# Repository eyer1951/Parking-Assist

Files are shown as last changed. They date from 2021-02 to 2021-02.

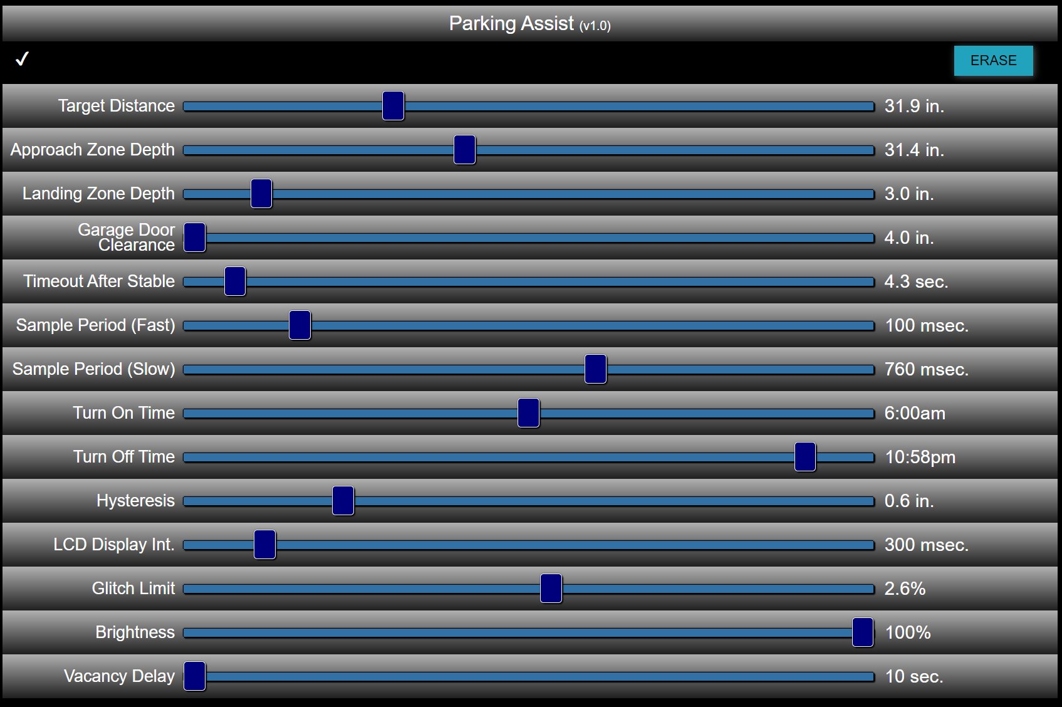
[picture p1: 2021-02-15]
images/web-app.jpg

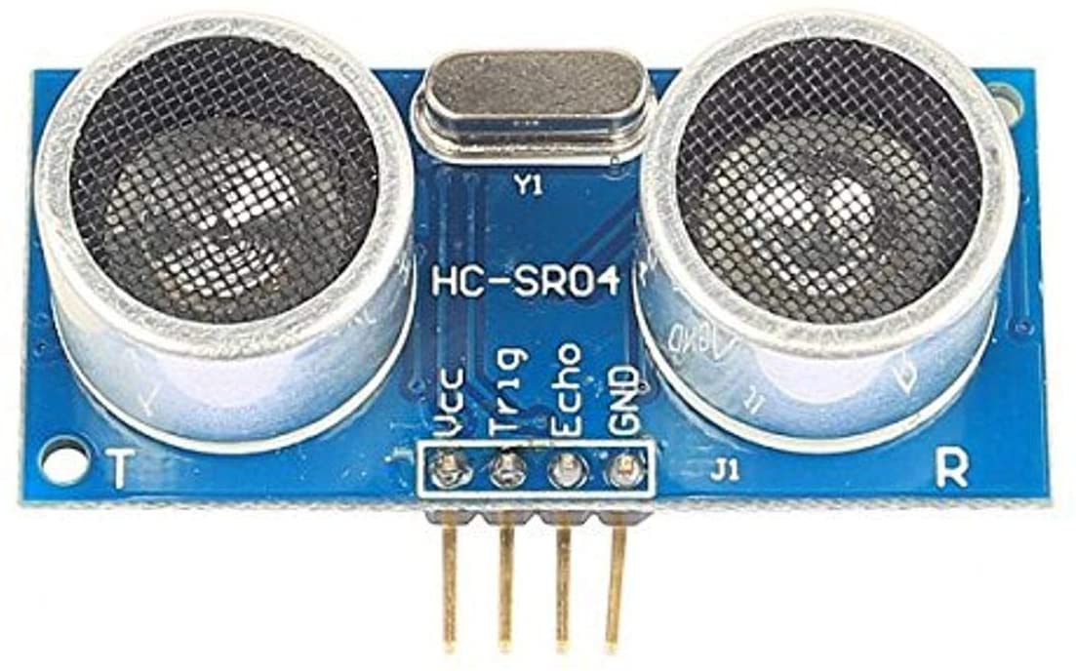
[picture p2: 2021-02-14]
images/HC-SR04_.jpg

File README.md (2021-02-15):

# Parking-Assist
ESP32-based parking assistant using ultrasonic distance measurement and a multi-LED display
This project was an opportunity to combine several hardware/software technologies to create something I use every day. 
The Parking Assist unit used an HC-SR04 ultrasonic distance sensor to help signal the precise positioning of the car 
as it is moved into the garage. The unit was mounted on the side of a file cabinet in front of my parking space.
Here's a view from inside the car as the driver pulls in:



Technologies, in addition to the use of the HC-SR04, include:

*	Control of an addressable (WS2812B) LED strip via the FastLED library

*	Sensing the ambient air temperature to compute an accurate speed of sound for distance measurement

*	WiFi connection to the home network for control

*	Setting the “target” parking distance via pushbutton

*	Setup of parameters by web application

*	Web application implemented an approach where the characteristics of the set of control parameters were defined in a JSON file

*	Websocket interface for delivery of parameters

*	A telnet interface for debugging and/or monitoring the status of the unit from within the home network

*	Supported ArduinoOTA for code downloads over the network

*	mDNS for network address discovery

*	Parameters retained in the ESP32 using nonvolatile storage in the ESP32

*	A real-time clock, synchronized to an NTP time server, to turn off the unit during off-hours

*	Printed circuit board designed to fit within a standard plastic enclosure

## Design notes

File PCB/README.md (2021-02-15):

# Printed Circuit Board

The Fritzing (BETA version 0.9.3) program was used to create a PCB design, pictured here:



Extended Gerber (RS-274X) files were created and delivered to a PC fab house, PCBWay (pcbway.com), 
which delivered 10 boards in under one week at a total cost of $25 (including shipping).

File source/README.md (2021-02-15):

# ESP32 Source Code

The code was written in C++ using the PlatformIO development environment running in Visual Studio Code. 
There are four main files in the source:

* main.css – the main program, including setup() and loop().
 
* main.h – a header file defining some project-related items used by the project.css file, and defining the array of parameters used.

* project.css – code implementing functions common to many projects, including:

  *	NVS-related functionality including initialization, saving and restoring parameters
  *	Some helpful utility functions
  * mDNS-related functionality
  *	WiFi connection functions, including reconnection upon lost connection
  *	Over-the-air (OTA) code download functionality
  *	WebSockets functionality supporting the parameter array approach

* project.h – header file for the project, providing procedure declarations and definition of a Ring buffer class.

Library dependencies are:

* adafruit/Adafruit Unified Sensor, version 1.1.4 or above

* adafruit/DHT sensor library version 1.4.1 or above

*	arduino-libraries/NTPClient version 3.1.0 or above

*	m5ez/ezTime version 0.8.3 or above

*	fastled/FastLED version 3.4.0

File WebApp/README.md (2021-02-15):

# Web Application

For all of the different ESP32 projects I have built so far, it has been helpful to provide a user interface whereby various operating parameters could be set, 
and adjusted over time as needed. A general approach was developed, involving:

*	A browser-based user interface written in (of course) Javascript and HTML/CSS.

*	Use of Websockets to communicate between the project and the browser.

*	The ESP32 discovers and connects to the home network in station mode, sets up an mDNS identifier for TCP/IP, and then opens a WebSocket interface.

*	Parameters are represented by an array of up to 30 unsigned 32-bit integers.

*	The web application uses the mDNS ID to establish a WebSocket connection, then queries the project to retrieve the values of all parameters.

*	The ESP32 saves all parameters in nonvolatile storage (NVS).

*	Changes to any parameter are delivered immediately via the Websocket interface and saved in the ESP32 in NVS.

*	The set of parameters and definitions for the project are defined in a JSON document opened by the web application.

Note: because it loads a local JSON file, the web application must be served from a web server on your network rather than being executed as a file on 
the local computer (that is, unless you run the browser with “same origin policy” disabled). 
Otherwise you might see this kind of error in the JavaScript console: 

```Access to XMLHttpRequest at 'file:///C:/Users/ … /projectName.json' from origin 'null' has been blocked by CORS policy: Cross origin requests are only supported for protocol schemes: http, data, chrome, chrome-extension, chrome-untrusted, https.```

The JSON document, in addition to defining the name of the project (for the web page title), version number, and mDNS name, 
defines a number of operating parameters. Operating parameters can be values representable by range sliders, Boolean flags 
(represented by checkboxes), or colors established by “color picker” interface. The web interface for the present project did 
not utilize any checkboxes or color pickers and is shown here:

![](images/web-app.jpg)

The checkmark in the upper left indicates connectivity to the project. The “ERASE” button in the upper left is used to command the project to erase NVS, if needed.
The JSON document defines a number of characteristics of each range slider, including:

*	The name (label on left side)

* The minimum and maximum values of the slider.

*	The step size 

As an example of the latter, the time of day parameters are represented as a number of minutes since midnight, so a parameter that would represent midnight to noon would be specified with a range that goes from zero to 12 * 60 = 360. The name of that display function is “timeOfDay.” Other example display functions are:

*	percent – displays the slider as a whole percentage, where zero is all the way to the left and 100 is all the way to the right.

*	percentTenths – displayed as percent as above, but as a floating point number with one digit to the right of the decimal

*	tenths – displays the value of the slider, but divided by 10.

Other functions can be easily written as needed.

CSS can be included in the JSON definition of any range slider, to provide, for example, a horizontal bar or extra space associated with a given slider.
A link to the JSON document that produced the user interface above is https://github.com/eyer1951/Parking-Assist/blob/main/WebApp/pc/parkme.json.

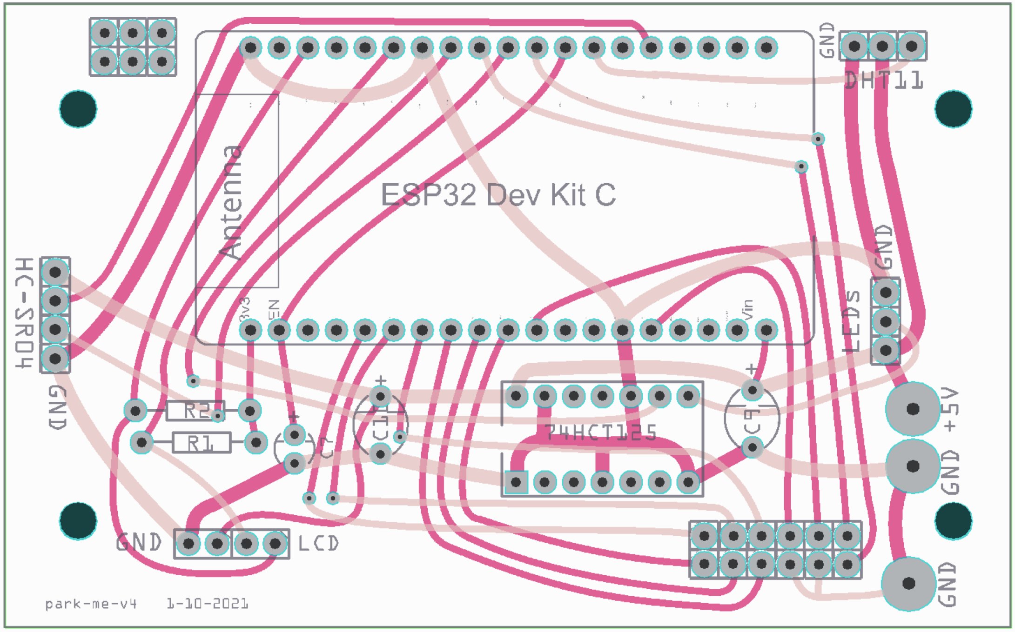
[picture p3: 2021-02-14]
images/PCB-gerber.jpg

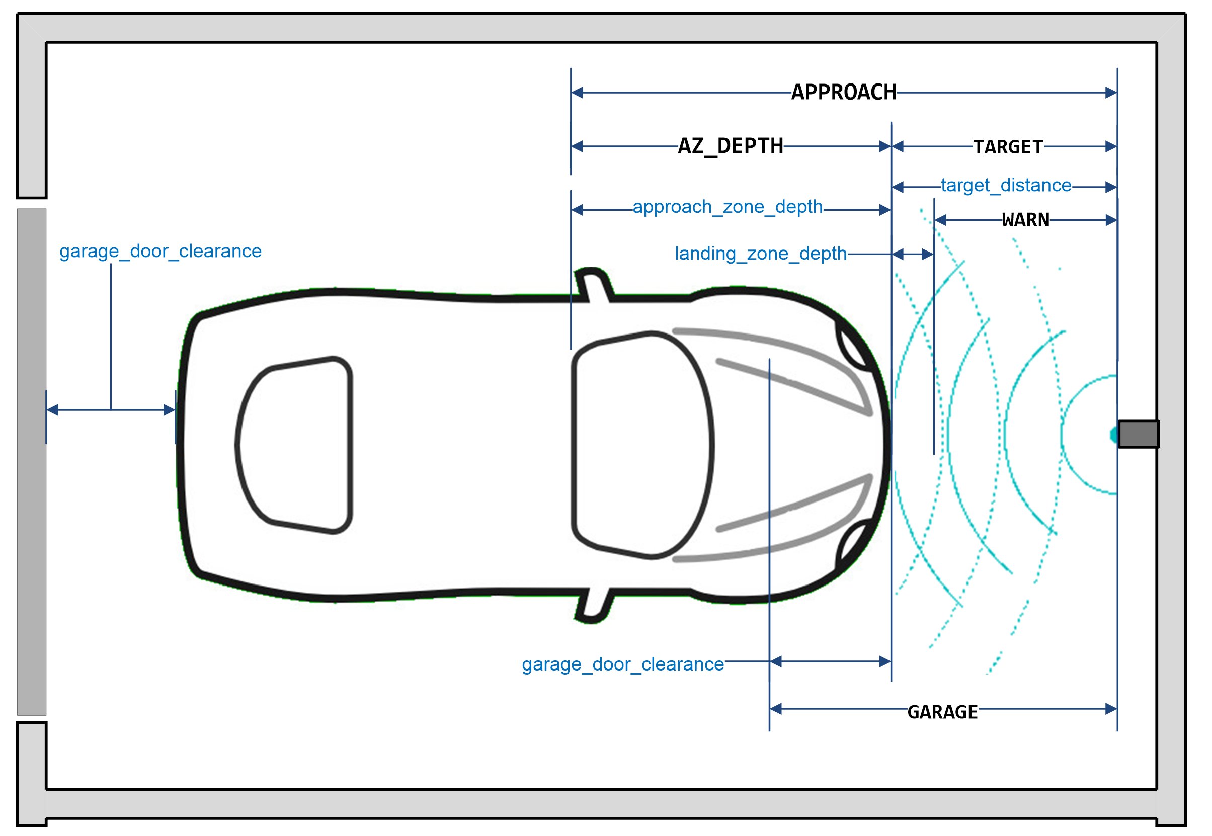
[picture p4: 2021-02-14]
images/Garage-params.jpg

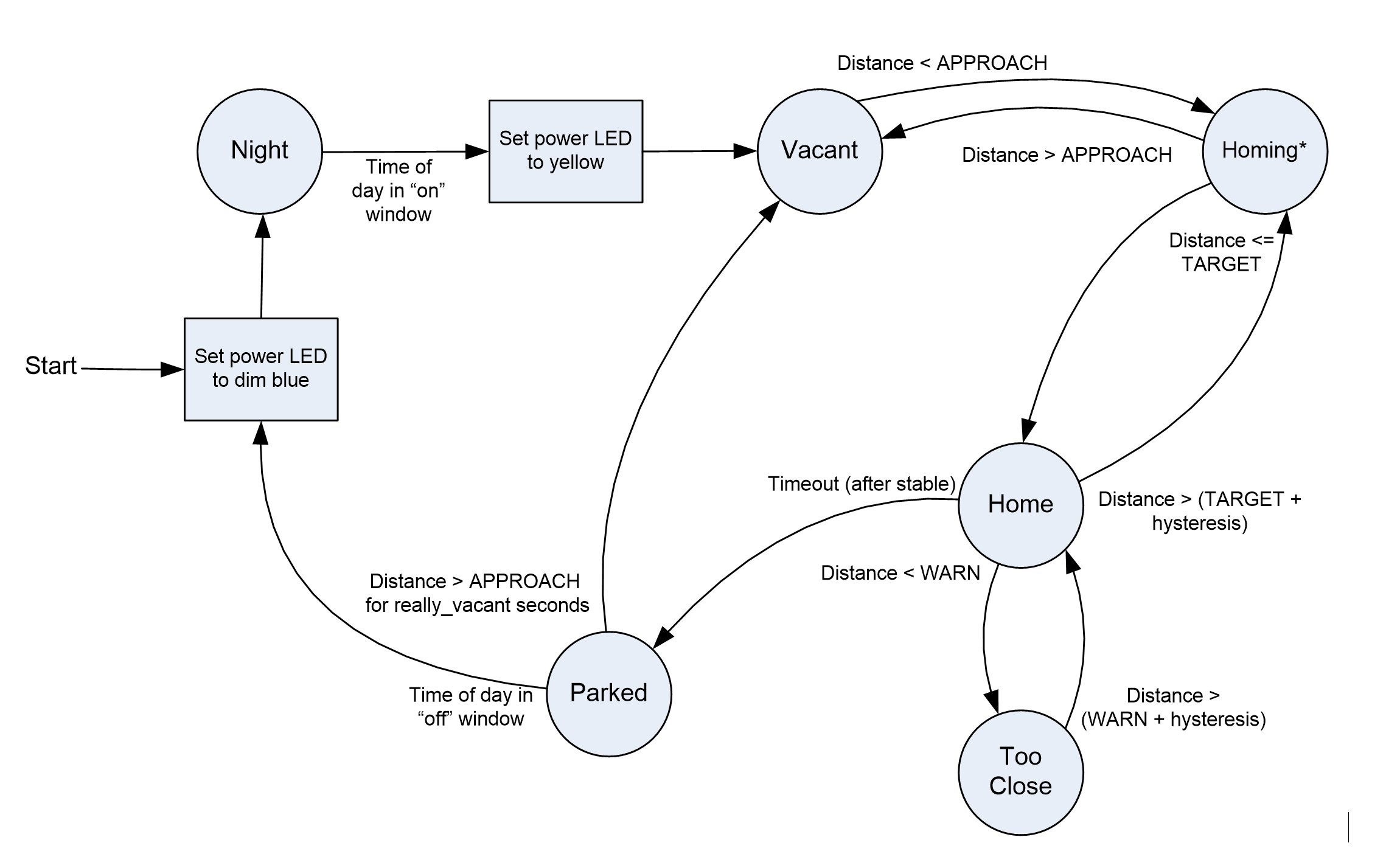
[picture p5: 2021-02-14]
images/Park-state-machine.jpg

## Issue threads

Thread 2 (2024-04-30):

Does anyone one have the file to flash the esp32?

TechsavvyCNC, 2024-04-30:
I'm having a lot off issues trying to build it on my own

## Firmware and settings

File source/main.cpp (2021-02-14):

/*Name:		Park-the-car.cpp
Created:	2/5/2021  1:40PM

STATUS:
    * Connects to home network, reconnects daily after network returns
    * API to control color of LED(s) 
      * (blink on startup to indicate code version)
    * Synchronizes to local time of day (including DST)
    * OTA upload 
    * Temperature, humidity, and distance sensor working
    * Turn system on in the morning and off at night based on settable parameters
    * Lower the sample rate to once every N msec. whenever distance is 
        * greater than threshold or less than threshold
    * Control color of LED (green to red) based on threshold values
    *   Or: number of LEDs lit in a strip
    * Blink red if beyond the "too close" threshold
    * Control of hysteresis
    * Control of brightness level when Homing
    * Supports Telnet connection, "D" command to report last 48 distance measurements
    * Supports mDNS, with "Parkme.local" (or "Parkme2.local") as host ID
*/
char version[] = "Park v1.14";

#include <Arduino.h>
#include <ArduinoOTA.h>
#include <ezTime.h>
#include <stdio.h>
#include <stdlib.h>
#include <string.h>
#include <cstring>
#include <math.h>
#include "driver/gpio.h"
#include "soc/gpio_struct.h"
#include "nvs.h"
#include "nvs_flash.h"

#define FASTLED_INTERNAL
#include <FastLED.h>
#include <Adafruit_Sensor.h>    // https://github.com/adafruit/Adafruit_Sensor
#include <DHT.h>                // https://github.com/adafruit/DHT-sensor-library
#include <LiquidCrystal_I2C.h>  // Library for LCD

#include "main.h"
#include "project.h"

//------------------------------------------ Options -------------------------------------------------
#define ENABLE_TIME_OF_DAY
// #define ENABLE_LCD

//----------------------------------------- GPIO Assignments -----------------------------------------
#define DHTPin 4        // I/O Pin for DHT11 Humiture unit 
#define DHTPin_ALT 26   // Alternate DHT11 pin (if GPIO4 doesn't work for all ESP32s)
#define DHTType DHT11   // Define DHT sensor type

#define trigPin 2       // I/O Pins for HC-SR04 Ultrasonic Distance Unit
#define echoPin 5

#define BUTTON_PIN 13   // Pushbutton is on GPIO13

#ifdef ENABLE_LCD
// Connect to LCD via i2c, default address 0x27 (A0-A2 not jumpered):
// LCD uses default i2c pins:  SCLPin = 22  SDAPin = 21
LiquidCrystal_I2C lcd = LiquidCrystal_I2C(0x27, 16, 2);
#endif

//------------------------------------------- DEBUG Items --------------------------------------------
#define CORE_DEBUG_LEVEL ESP_LOG_ERROR
#define GPIO_DEBUG
#define DEBUG_TICKS 1 /* How many cycles debug_time > 0 */
#define DEBUG_INTERVAL_MS 500
volatile int debug_time = 0;

// ------------------------------------------- LED STUFF ---------------------------------------------
#define NUM_LEDS 16
#define NUM_STRANDS 1 

#define COLOR_ORDER GRB
#define CHIPSET WS2812B
#define BRIGHTNESS 128
#define MAX_BRIGHTNESS 255
#define MY_CORRECTION 0xFEC886 /* set by testing */
#define RMT_CH0_GPIO 19
#define MAX_LED_BRIGHTNESS parameters[max_led_brightness_pct] * 255 / 100
static CRGB leds[NUM_STRANDS][NUM_LEDS + 1];  // the +1 holds overflow (not visible)

//---------------------------------------------- Globals ---------------------------------------------
using namespace std;

#define PRESSED LOW
#define NOT_PRESSED HIGH

typedef struct Buttons {
    const byte pin = BUTTON_PIN;
    const int debounce = 10;
 
    unsigned long counter=0;
    bool prevState = NOT_PRESSED;
    bool currentState;
} Button;
 
// create a Button variable type
Button button;

long duration;
float distance_cm;
float distance_in;
float distance_ft;
float speedofsound;
float parked_at;
float state_distance;

int temperature;
unsigned long msnow = millis();
unsigned long home_time_ms;

extern nvs_handle my_nvs_handle;
extern Params parameters;
extern WebSocketsServer webSocket;
extern char base_hostname[30];

const char *base_ssid = BASE_SSID;
const char *base_password = BASE_PASSWORD;

#ifdef ENABLE_TIME_OF_DAY
Timezone myTZ;
int hour_now = myTZ.hour();
int minute_now = myTZ.minute();
int second_now = myTZ.second();
#endif

// Queue of distance measurements, for smoothing
int dist_iptr = 0;
int dist_optr = 0;
#define DIST_Q_DEPTH 100
float distances[DIST_Q_DEPTH];

// Blink warning
#define BLINK_INTERVAL 300  // milliseconds
bool blink;

typedef Ring<float> Ringf;
typedef Ring<long> Ringi;

Ringf samples_f(DIST_Q_DEPTH);
Ringi samples_i(DIST_Q_DEPTH);
int skipped = 0;
int skipped_total = 0;

//------------------------------------------ Parameters ----------------------------------------------
Parameter params[NO_OF_PARAMS] = {{"target distance (tenth in.)", 450},
                                  {"approach zone depth (tenth in.)", 480},
                                  {"landing zone depth (tenth in.)", 50},
                                  {"garage door clearance (tenth in.)", 100},
                                  {"timeout after stable (sec.)", 600},
                                  {"high precision sample rate (msec.)", 200},
                                  {"background sample rate (msec.)", 1500},
                                  {"time turn on (minutes since midnight)", 70},
                                  {"time turn off (minutes since midnight)", 230},
                                  {"hysteresis (tenth in.)", 15},
                                  {"lcd display interval (msec.)", 300},
                                  {"glitch limit (pct. x10)", 50},
                                  {"brightness (pct.)", 100},
                                  {"vacancy delay (sec.)", 60}};

//------------------------------------------ State Machine -------------------------------------------
enum State {Night, Vacant, Homing, Home, TooClose, Parked};
State state = Night;

unsigned long display_interval, measurement_interval;
SemaphoreHandle_t xSemaphore_d = NULL;   // distance
SemaphoreHandle_t xSemaphore_t = NULL;   // temperature

#define TEMP_MEASUREMENT_INTERVAL_MS  1000 * 60 /*  1000 * 60 * 5 5 minutes */

#define LONG_TIME 0xFFFFFF

#define UNIT_NO_PIN 27  /* Pulldown when not the one in the garage; for testing */

extern WiFiClient serverClient;
extern tcpip_adapter_ip_info_t info;

DHT dht1(DHTPin, DHTType);
DHT dht2(DHTPin_ALT, DHTType);
DHT *dhtp;
int unit_no;

//-------------------------------------------- LCD Stuff ---------------------------------------------
#ifdef ENABLE_LCD
SemaphoreHandle_t xSemaphore_l = NULL;   // LCD
#define LCD_BUFFSIZE 20
char buffer1[LCD_BUFFSIZE];  // LCD line 1
char buffer2[LCD_BUFFSIZE];  // LCD line 2
#define LCD_DISPLAY_INTERVAL parameters[lcd_display_interval_ms]

void display_off_on_lcd() {
    memset(buffer1, 0, sizeof(buffer1));
    strcpy(buffer1, "off");
    memset(buffer2, 0, sizeof(buffer2));
}
#endif

//------------------------------------------- Telnet -------------------------------------------------
// Telnet
WiFiServer server(23);
WiFiClient serverClient;

// ------------------------------------------ Telnet Print -------------------------------------------
template<typename... Args> void telnet_printf(const char * f, Args... args) {
    char cbuff [360];
    int len;
    if (serverClient || serverClient.connected()) {
        len = sprintf(cbuff, f, args...);
        if (cbuff[len-1] == '\n') cbuff[len++] = '\r';
        serverClient.write(cbuff, len); 
    }
}

template<typename... Args> void tprintf(const char * f, Args... args) {
    printf(f, args...);
    telnet_printf(f, args...);
    telnet_printf("\r");
}

void handle_telnet_command(char c) {
    float items[51], a;
    string results = "";
    char one_item[30];
    int i, n;
    switch (c) {
        case 'D':
        case 'd':
            n = samples_f.get_last_n(49, items);
            for (i = 0; i < 49; i ++) {
                if (i < n) {
                    sprintf(one_item, "%.1f, ", items[i]);
                    results += one_item;
                }
            }
            a = samples_f.average(4);
            telnet_printf("%s (%.1f)\n\r", results.c_str(), a);
            break;
        default:
            break;
    }
}

void new_telnet_client() {
    if (WiFi.status() == WL_CONNECTED) {
        if (server.hasClient()) {
            if (!serverClient || !serverClient.connected()) {
                if (serverClient) serverClient.stop();
                serverClient = server.available();
                if (!serverClient) printf("available broken\n");
                telnet_printf("New telnet client: %s\n\r", serverClient.remoteIP().toString().c_str());
                telnet_printf("\n\e[0;32mConnected to %s on channel %i\e[0m\n\r", BASE_SSID, WiFi.channel());
                tcpip_adapter_get_ip_info(TCPIP_ADAPTER_IF_STA, &info);
                telnet_printf("Got IP address %s\n\r", ip4addr_ntoa(&info.ip));
            }
        }
        if (serverClient && !serverClient.connected()) {
            serverClient.stop();
        }
    }
}

void check_telnet_data() {
    char cbuff[10];
    if (serverClient && serverClient.connected()) {
        if (serverClient.available()) {
            while (serverClient.available()) {
                cbuff[0] = serverClient.read();
                handle_telnet_command(cbuff[0]);
            }
        }
    }
}

//------------------------------------------ Button Handler ------------------------------------------
void handle_button_press() {
    float where_we_are = samples_f.average(samples_f.fullness()-1);
    parameters[target_distance_10th_in] = (int)(0.5 + where_we_are * 10.0);
    tprintf("New target distance set to %.1f inches (%i)\n", where_we_are, parameters[target_distance_10th_in]);
    send_parameters(255);
    save_params();
}

void check_button() {
    button.currentState = digitalRead(button.pin);    // check the button
    if (button.currentState != button.prevState) {    // has it changed?
        delay(button.debounce); 
        button.currentState = digitalRead(button.pin);  // update status in case of bounce
        if (button.currentState == PRESSED) { // has a new press event occured?
            handle_button_press();
        }
        button.prevState = button.currentState; // used to detect when state changes
    } 
}

//------------------------------------------ Time of Day ---------------------------------------------
#ifdef ENABLE_TIME_OF_DAY
void wait_for_local_time() {
	//setDebug(INFO);
	waitForSync();
	printf("UTC:         %s\n", UTC.dateTime().c_str());
	// https://en.wikipedia.org/wiki/List_of_tz_database_time_zones
	myTZ.setLocation(F(MY_TIME_ZONE));
	printf(MY_CITY ":     %s\n", myTZ.dateTime().c_str());
}
#endif

bool during_the_day() {
#ifndef ENABLE_TIME_OF_DAY
    return true;
#else
    int hour_now = myTZ.hour();
    int minute_now = myTZ.minute();
    int since_midnight = (hour_now * 60) + minute_now;
    bool too_early = since_midnight < parameters[hour_turn_on];
    bool too_late = since_midnight > parameters[hour_turn_off];
    return !too_early && !too_late;
#endif
}

// ---------------------------------------- DISPLAY STUFF --------------------------------------------
void clear_leds() { memset(leds, 0, sizeof(leds)); }

void show_version() {
    // Blink the LED corresponding to version LSB
    int z[10] = {0, 6, 2, 8, 4, 1, 7, 3, 9, 5};  // sequence colors semi-randomly
    int i, n, v, h, d;
    CHSV c;
    n = strlen(version);
    v = version[n - 1] - '0';
    h = 255 * z[v] / 10;
    c = CHSV(h, 255, 255);
    if (v > 0)
        d = 150;
    else {
        d = 50;  // LSB zero -> short blink hue 0
        v++;
    }
    for (i = 0; i < v; i++) {
        leds[0][0] = c;
        FastLED.show();
        delay(d);
        leds[0][0] = CRGB::Black;  
        FastLED.show();
        delay(300);
    }
}

void flash_a_light() {
        leds[0][1] = CRGB::White;
    FastLED.show();
    delay(20);
    leds[0][1] = CRGB::Black;
    FastLED.show();
}

void set_all_leds(CRGB c) {
    for (int i = 0; i < NUM_LEDS; i++) {
        leds[0][i] = c;
    }
    FastLED.show();
}

#define TARGET parameters[target_distance_10th_in] / 10.0
#define AZ_DEPTH parameters[approach_zone_depth_10th_in] / 10.0
#define WARN (parameters[target_distance_10th_in] - parameters[landing_zone_depth_10th_in]) / 10.0
#define GARAGE (parameters[target_distance_10th_in] + parameters[garage_door_clearance_10th_in]) / 10.0
#define APPROACH (parameters[target_distance_10th_in] + parameters[approach_zone_depth_10th_in]) / 10.0
#define HYSTERESIS parameters[hysteresis_10th_in] / 10.0

void show_homing_leds() {
// light top LED white
    float d = samples_f.average(5);
    uint8_t h;
    int max_leds = NUM_LEDS - 1;
    float home = TARGET + 0.5 * AZ_DEPTH;
    clear_leds();
    if (d < WARN) return;
    if (d > home) {
        leds[0][max_leds] = CRGB::White;
        FastLED.show();
        return;
    } 
    // if closer than warning distance, light some other LEDs
    float num_lit_f = max_leds - max_leds * (d - TARGET) / (home - TARGET);  // ok
    int num_lit_i = (int)num_lit_f;
    // compute fractional value for LED one beyond the last one fully lit
    float frac_lit = num_lit_f - num_lit_i;
    uint8_t value = frac_lit * MAX_LED_BRIGHTNESS;
    h = 96 - (36 * num_lit_i / max_leds);  // hue goes from green to yellow as we get closer
    for (int i = 0; i < num_lit_i; i++) {
        leds[0][i] = CHSV(h, 255, MAX_LED_BRIGHTNESS);
    }
    // determine a color/value for fractional LED
    CHSV frac = CHSV(h, 255, value);
    CRGB colo = frac;
    if (colo.green < 2 && colo.blue == 0) colo.red = 0;  // no red-only display
    leds[0][num_lit_i] = colo;
    leds[0][max_leds] = CRGB::White;
    if (d > GARAGE)
        leds[0][0] = CRGB::Red;
    FastLED.show();
    vTaskDelay(10);
}

// ----------------------------------------- SPEED OF SOUND ------------------------------------------
void derive_speed_of_sound() {
    int temp_temp;
    temp_temp = dhtp->readTemperature();
    if (temp_temp < 40 && temp_temp > 10)
        temperature = temp_temp;
    else
        return;
    // Calculate speed of sound in m/s:
    speedofsound = 331.3 + (0.606 * temperature);
}

// --------------------------------------------- DISTANCE --------------------------------------------
void measure_distance() {
    float delta_pct;
    long diff;
    digitalWrite(trigPin, LOW);
    delayMicroseconds(5);
    // Trigger the sensor by setting the trigPin high for 10 microseconds:
    digitalWrite(trigPin, HIGH);
    delayMicroseconds(10);
    digitalWrite(trigPin, LOW);

    // Read the echoPin. This returns the duration (length of the pulse) in microseconds:
    long d = pulseIn(echoPin, HIGH);
    if (samples_i.fullness() >=3) {
        long ave = samples_i.average(3);
        if (d > ave) {
            diff = d - ave;
        } else {
            diff = ave - d;
        }
        delta_pct = 1000.0 * (float)diff / (float)ave;  // percent would be x100, but parameter is 10x percent, so x1000
        // add this sample to the queue IF 
        //  * we skipped the previous one, OR
        //  * the sample does not differ from the average by an amount larger than "glitch limit", OR
        //  * we are in Vacant state 
        if (skipped || delta_pct < parameters[glitch_limit_pct] || state == Vacant) {
            samples_i.add(d);
            skipped = 0;
        } else {
            skipped ++;
            skipped_total ++;
        }
    } else {
        samples_i.add(d);
        skipped = 0;
    }
    duration = samples_i.average(3);
    // Calculate the distance in cm:
    distance_cm = duration * (speedofsound / 10000) / 2;
    distance_in = distance_cm / 2.54;
    distance_ft = distance_in / 12.0;
    samples_f.add(distance_in);
}

//------------------------------------------------ Initialization ------------------------------------
static void initialize_humiture() {
    pinMode(trigPin, OUTPUT);
    pinMode(echoPin, INPUT);
    if (unit_no == 0)
        dhtp = &dht2;
    else
        dhtp = &dht1;
    dhtp->begin();
#ifdef ENABLE_LCD
    // Initiate the LCD:
    lcd.init();
    lcd.backlight();
#endif
}

void gpioSetup(int gpioNum, int gpioMode, int gpioVal) {
#if defined(ARDUINO) && ARDUINO >= 100
    pinMode(gpioNum, gpioMode);
    digitalWrite(gpioNum, gpioVal);
#endif
}

// ------------------------------------------ Setup Tasks --------------------------------------------
void per_second_task(void *pvParameters) {
    while (1) {
        maybe_save_params();
        vTaskDelay(1000 / portTICK_PERIOD_MS);
    }
}

void temperature_task(void *pvParameters) {
    xSemaphore_t = xSemaphoreCreateBinary();
    while (1) {
        if( xSemaphoreTake( xSemaphore_t, LONG_TIME ) == pdTRUE )    
            if (state != Night) {
                    derive_speed_of_sound();
                }
       vTaskDelay(10);
    }
}

void distance_task(void *pvParameters) {
    xSemaphore_d = xSemaphoreCreateBinary();
    while (1) {
        if( xSemaphoreTake( xSemaphore_d, LONG_TIME ) == pdTRUE )    
            measure_distance();
    }
}

#ifdef ENABLE_LCD
void show_values_on_lcd_task(void *pvParameters) {
    xSemaphore_l = xSemaphoreCreateMutex();
    while (1) {
        if (xSemaphoreTake( xSemaphore_l, LONG_TIME) == pdTRUE) {
            lcd.setCursor(0, 0);
            vTaskDelay(2);
            lcd.printstr(buffer1);
            vTaskDelay(2);
            lcd.setCursor(0, 1);
            vTaskDelay(2);
            lcd.printstr(buffer2);  
            vTaskDelay(2);
//            xSemaphoreGive( xSemaphore_l);
        }
    }
}
#endif

void blink_task(void *pvParameters) {
    while (1) {
        vTaskDelay(BLINK_INTERVAL);
        blink = !blink;
    }
}

void main_loop(void *pvParameters);

void initialize_tasks() {
    xTaskCreatePinnedToCore(per_second_task, "per_second_task", 2048, NULL, 2, NULL, 0);
    xTaskCreatePinnedToCore(temperature_task, "temperature_task", 2048, NULL, 3, NULL, 1);
    xTaskCreatePinnedToCore(blink_task, "blink_task", 2048, NULL, 4, NULL, 0);
    xTaskCreatePinnedToCore(distance_task, "distance_task", 4096, NULL, 10, NULL, 1);
#ifdef ENABLE_LCD
    xTaskCreatePinnedToCore(show_values_on_lcd_task, "LCD", 4096, NULL, 10, NULL, 1);
#endif
    xTaskCreatePinnedToCore(main_loop, "main", 4096, NULL, 9,  NULL, 1);
}

void initialize_gpio() {
    pinMode(UNIT_NO_PIN, INPUT_PULLUP);
    pinMode(button.pin, INPUT_PULLUP);
}

void initialize_FastLED() {
    clear_leds();
    FastLED.addLeds<CHIPSET, RMT_CH0_GPIO, COLOR_ORDER>(leds[0], NUM_LEDS)
        .setCorrection(TypicalLEDStrip);
    FastLED.setBrightness(MAX_BRIGHTNESS);
    FastLED.setMaxRefreshRate(100);
    FastLED.setDither(0);
}

// --------------------------------------------- Transition State ------------------------------------
// {Night, Vacant, Homing, Home, TooClose, Parked}
void go_Night() {
    tprintf("to Night\n");
    display_interval = 1000;  // per second
    measurement_interval = 0;  // no measurements
#ifdef ENABLE_LCD
    display_off_on_lcd();
#endif
    state = Night;
}

void go_Vacant() {
    display_interval = 100;  // 10 per second
    measurement_interval = parameters[background_sample_per_msec];
    state = Vacant;
}

void go_Homing() {
    display_interval = 20;  // 50 displays per second
    measurement_interval = parameters[high_precision_sample_per_msec];
    state = Homing;
}

void go_Home() {
    home_time_ms = millis();
    display_interval = 20;  // 50 displays per second
    measurement_interval = parameters[high_precision_sample_per_msec];
    state = Home;
}

void go_TooClose() {
    state = TooClose;
    display_interval = 100;  // 10 per second
    measurement_interval = parameters[high_precision_sample_per_msec];
}

void go_Parked() {
    display_interval = 100;  // 10 per second
    measurement_interval = parameters[background_sample_per_msec];
    state = Parked;
    parked_at = samples_f.average(3);
}

void initialize_base_hostname() {
    strcpy(base_hostname,MDNS_HOST);
    if (unit_no == 0)  // Second (test) unit? 
        strcat(base_hostname, "2");
//    strcat(base_hostname, ".local");
}

// ---------------------------------------------- SETUP ----------------------------------------------
void setup() {
    initialize_gpio();
    unit_no = gpio_get_level((gpio_num_t)UNIT_NO_PIN);
    initialize_base_hostname();
    initialize_FastLED();
    // leds[0][NUM_LEDS - 1] = CRGB{5, 0, 5};   // for debug: in case of some early crach
    // FastLED.show();
    initialize_project();
    initialize_humiture();

    printf("Showing version...\n");
    show_version();
    printf("Restoring parameters...\n");
    restore_parameters(params, NO_OF_PARAMS);
#ifdef ENABLE_TIME_OF_DAY
    printf("Getting time of day...\n");
    wait_for_local_time();
#endif
    printf("High precision sample period (msec.): %i\n", parameters[high_precision_sample_per_msec]);
    derive_speed_of_sound();
    go_Night();

    printf("initializing tasks...\n");
    initialize_tasks();
    samples_f.reset();
}

// ---------------------------------------------- IDLE -----------------------------------------------
void idle(int idle_ms) {
    uint32_t now;
    now = millis();
    while (millis() - now < idle_ms) {
        ArduinoOTA.handle();
        webSocket.loop();
        new_telnet_client();
        check_telnet_data();
        vTaskDelay(1);
        check_button();
    }
}
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
void loop() {
    for (;;)
    ;
}

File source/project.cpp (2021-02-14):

/*
    project.cpp -- 13 January 2021

    This library provides the following functionality for projects:
    * Connection to a local WiFi access point, automatically retries if connection lost
    * Establishes an MDNS local network address
    * Supports configurability by a set of parameters defined by the project
    * Parameters can be set/changed by a web application based on a JSON config file
    * main.h header file defines parameter names and default values
    * Parameters are saved in NVS, restored on boot
    * Parameters settable via Websocket interface
    * Each parameter is a 32-bit integer, so it can support FastLED HSV colors (359-255-255)
    * parameter[0] is flags
    * Responds to "Q" Websocket command to report all parameters to web app
*/
#include "project.h"
#include "main.h"
#include <Arduino.h>
#include <ArduinoOTA.h>
#include <ESPAsyncWebServer.h>
#include <WiFi.h>
#include <WiFiUdp.h>
#include <ESPmDNS.h>
#include <esp_wifi.h>
#include <WebSocketsServer.h>
#include "SPIFFS.h"
#include "nvs.h"
#include "nvs_flash.h"
#include <stdio.h>
#include <stdlib.h>
#include <string.h>
#include <cstring>
#include <esp_int_wdt.h>
#include <esp_task_wdt.h>

extern char version[];

#define ESP_MAXIMUM_RETRY 20
#define REATTEMPT_INTERVAL_MS  60 * 5 * 1000
#define HW_RESET_PIN 16

using namespace std;

nvs_handle my_nvs_handle;
static EventGroupHandle_t task_group;
static EventGroupHandle_t s_wifi_event_group;
const int WIFI_CONNECTED_BIT = BIT0;
static int s_retry_num = 0;
tcpip_adapter_ip_info_t info;
bool params_changed = false;
Params parameters;
WebSocketsServer webSocket(81);
char base_hostname[30];

#define PLEASE_STOP_MAIN_BIT 1
static int WSopen = 0;  // true/false, is WS connection open?
extern WiFiServer server;

// ---------------------------------------------- NVS ------------------------------------------------
void send_param_set(uint8_t num);
void immediately_set(string s);

void initialize_nvs() {
    esp_err_t ret;
    ret = nvs_flash_init();
    if (ret == ESP_ERR_NVS_NO_FREE_PAGES) {
        ESP_ERROR_CHECK(nvs_flash_erase());
        ret = nvs_flash_init();
    }
    ESP_ERROR_CHECK(ret);
//    ESP_LOGI(TAG, "Opening Non-Volatile Storage(NVS) handle");
    ret = nvs_open("storage", NVS_READWRITE, &my_nvs_handle);
    if (ret != ESP_OK) ESP_LOGE(TAG, "Error [%s] opening NVS handle!", esp_err_to_name(ret));
}

bool save_params() {
    size_t size = sizeof(parameters);
    params_changed = false;
    if (nvs_set_blob(my_nvs_handle, "Params", &parameters, size) != ESP_OK) {
        printf("Error saving parameters\n");
        return false;
    }
    return true;
}

void restore_parameters(Parameter * p, int count) {  // fetch parameters from NVS if available
    Params x;
    esp_err_t ret;
    size_t size = sizeof(Params);
    ret = nvs_get_blob(my_nvs_handle, "Params", &x, &size);
    if (ret == ESP_OK) {
        memcpy(parameters, x, size);
        printf("Restored flags to %u\n", parameters[flags]);
        for (int i = 0; i < NO_OF_PARAMS; i ++) {
            printf(" - %s to %u\n", p[i].readable_name.c_str(), parameters[i + 1]);
        }
   } else {
        printf("Using default parameter values (%i)\n", int(ret));
        printf("flags: 0\n");
        for (int i = 0; i < NO_OF_PARAMS; i ++) {
            printf("Set %s to %u default\n", p[i].readable_name.c_str(),p[i].default_value);
            parameters[i + 1] = p[i].default_value;
        }
        save_params();
    }
}

// ------------------------------------------ Utilities ----------------------------------------------
string int_to_string(int i) {
	string s;
	int r = i % 10;
	s = (char)(r + 48);
	i = (i - r) / 10;
	r = i % 10;
	while (i > 0) {
		s = (char)(r + 48) + s;
		i = (i - r) / 10;
		r = i % 10;
	}
	return s;
}

int str_to_int(string s) {
    int r = 0, m = 1;
    if (!s.length()) return 0;
    for (int i = s.length() - 1; i >=0; i--) {
        r += ((uint8_t)s[i] - 48) * m;
        m *= 10;
    }
    return r;
}

void printHexArray(uint8_t *arr, uint8_t len) {  // for testing;  groups of 4 bytes per line
    for (int i = 0; i < len; i++) {
        printf("%.2X ", arr[i]);
        if (i % 4 == 3) printf("\n");
    }
}

// -------------------------------------------- mDNS Stuff -------------------------------------------
bool start_mdns() {
    esp_err_t err = mdns_init();
    if (err) {
        printf("MDNS Init failed: %d\n", err);
        return false;
    }

    //set hostname
    mdns_hostname_set(&base_hostname[0]);
    mdns_service_add(NULL, "_http", "_tcp", 80, NULL, 0);
    mdns_service_add(NULL, "_ws", "_tcp", 81, NULL, 0);
    esp_err_t e = mdns_service_add(NULL, "_ping", "_tcp", 22, NULL, 0);
    printf("MDNS Services added for %s (%i)\n", base_hostname, e);
    return true;
}

// ----------------------------------------------- OTA -----------------------------------------------

void hardwareReset() {
    pinMode(HW_RESET_PIN, OUTPUT);
    digitalWrite(HW_RESET_PIN, false);
    delay(2000);
}

static void initialize_OTA() {
    ArduinoOTA.onStart([]() {
        string stype;
        if (ArduinoOTA.getCommand() == U_FLASH)
            stype = "sketch";
        else  // U_SPIFFS
            stype = "filesystem";
        // arrange for main loop to stop
        xEventGroupSetBits(task_group, PLEASE_STOP_MAIN_BIT);
        printf("Starting OTA update of %s\n", stype.c_str());
    });
    ArduinoOTA.onEnd([]() {
        printf("\n\e[0;32mSUCCESS!\e[0m\nHardware reset via GPIO16...\n");  // '\e[0;32m' sets green text mode
        delay(100);  // let the printf finish before self-reset
        hardwareReset();
    });
    ArduinoOTA.onProgress([](unsigned int progress, unsigned int total) {
        Serial.printf("Progress: %u%%\r", (progress / (total / 100)));
    });
    ArduinoOTA.onError([](ota_error_t error) {
        printf("\n");
        printf("Error[%u]: ", error);
        if (error == OTA_AUTH_ERROR)
            printf("Auth Failed\n");
        else if (error == OTA_BEGIN_ERROR)
            printf("Begin Failed\f");
        else if (error == OTA_CONNECT_ERROR)
            printf("Connect Failed\n");
        else if (error == OTA_RECEIVE_ERROR)
            printf("Receive Failed\n");
        else if (error == OTA_END_ERROR)
            printf("End Failed\n");
        xEventGroupClearBits(task_group, PLEASE_STOP_MAIN_BIT);
    });

    ArduinoOTA.begin();
}
// ------------------------------------------ WebSockets --------------------------------------------------
void send_parameters(uint8_t num) {
// num=255 indicates broadcast
    String s3 = "Q[";
    for (int i = 0; i < PARAM_COUNT - 1; i++) {
        s3 += String(parameters[i]) + ",";
    }
    s3 += String(parameters[PARAM_COUNT - 1]) + "]";
    printf("[Q]: %s\n", s3.c_str());
    if (num < 255)
        webSocket.sendTXT(num, s3.c_str());
    else 
        webSocket.broadcastTXT(s3);
}
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
